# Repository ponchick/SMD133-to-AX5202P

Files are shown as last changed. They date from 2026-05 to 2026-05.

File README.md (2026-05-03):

# SMD133-to-AX5202P

Adapter PCB from the SMD133 mapper IC to the MMC3 AX5202P.

Several cartridge projects are designed for the AX5202P, but that chip is hard to find, whereas the SMD133 is easier to obtain. This board lets you use the SMD133 in those projects.

Russian version: [`README.ru.md`](README.ru.md)

## Jumper configuration

### `K5K7`

The **K5K7** jumper (on SMD133A the corresponding pin is labeled **K5K6**, on SMD133B — **K5K7**) selects which **additional** register block is active on the SMD133.

- If the jumper is **closed**, the range `$5000–$5005` is used.
- If the jumper is **open** (left open), the range depends on the SMD133 variant:
  - SMD133A → `$6000–$6005`
  - SMD133B → `$7000–$7005`

**Note:** With the jumper open, the chip’s internal pull-down holds the pin to GND. If you want to drive this signal from an external source (for example, from the cartridge PCB), solder to the matching pad on the board and do not bridge the jumper. A closed jumper, conversely, pulls the pin to VCC.  
If you are not planning to experiment with the SMD133, the simplest approach is to leave the jumper unsoldered — this does not affect MMC3 mapper operation.

### `CPU_A1` and `CPU_A12`

The AX5202P does not have these pins, but the SMD133 does.  
These jumpers let you either bring in external address-line signals (for example, from the cartridge PCB) or tie them to ground.

- **Close the jumpers** — the corresponding SMD133 pins are forced to GND. This yields behaviour close to authentic MMC3.
- **Leave them open** — you can feed `CPU_A1` and `CPU_A12` from external circuitry by soldering to the jumper pads.

**Important:** It is not recommended to leave these pins floating (connected neither to ground nor to an external signal). In theory this could lead to unpredictable mapper behaviour, although no one has deliberately verified this.

### `WRAM +CE` and `WRAM WE`

These are **normally closed** jumpers:

- `WRAM +CE` is pulled to `VCC`.
- `WRAM WE` is shorted to the `CPU_RW` signal.

This wiring reproduces AX5202P behaviour, so it is recommended to leave the jumpers as-is.  
If you want to experiment — cut the corresponding jumper.

## License

This project is licensed under **CERN Open Hardware Licence Version 2 – Permissive** (`CERN-OHL-P-2.0`).  
See `LICENSE` for details.

SPDX-License-Identifier: `CERN-OHL-P-2.0`

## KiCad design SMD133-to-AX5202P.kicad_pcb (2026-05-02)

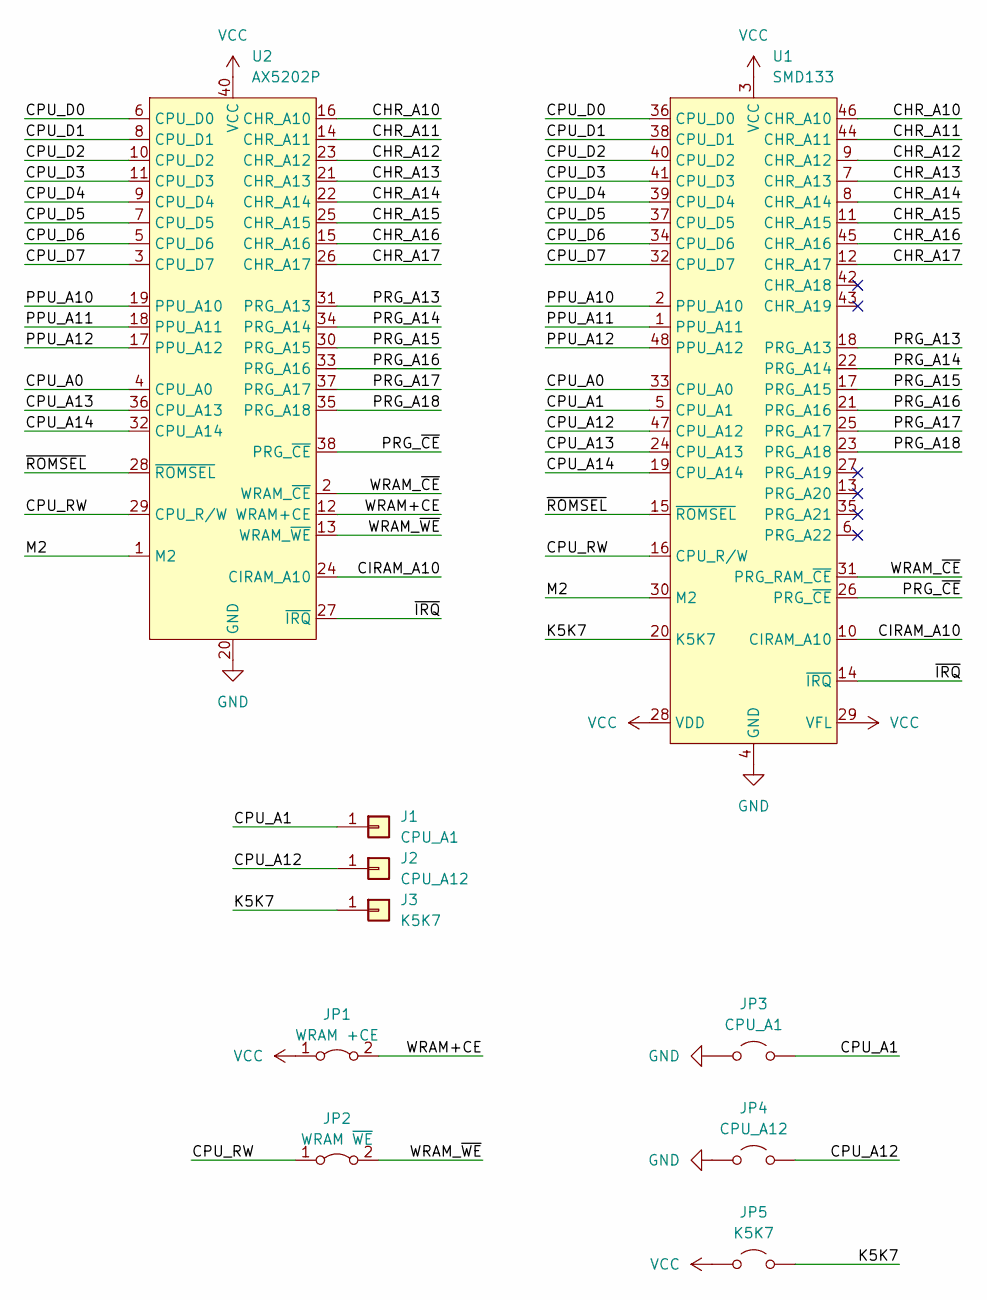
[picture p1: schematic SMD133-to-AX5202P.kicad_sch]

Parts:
J1: CPU_A1; TestPoint_THTPad_D2.0mm_Drill1.0mm
J2: CPU_A12; TestPoint_THTPad_D2.0mm_Drill1.0mm
J3: K5K7; TestPoint_THTPad_D2.0mm_Drill1.0mm
JP1: WRAM +CE; SolderJumper-2_P1.3mm_Bridged_Pad1.0x1.5mm
JP2: WRAM ~{WE}; SolderJumper-2_P1.3mm_Bridged_Pad1.0x1.5mm
JP3: CPU_A1; SolderJumper-2_P1.3mm_Open_TrianglePad1.0x1.5mm
JP4: CPU_A12; SolderJumper-2_P1.3mm_Open_TrianglePad1.0x1.5mm
JP5: K5K7; SolderJumper-2_P1.3mm_Open_TrianglePad1.0x1.5mm
U1: SMD133; LQFP-48_7x7mm_P0.5mm
U2: AX5202P; DIP-40_W15.24mm

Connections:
/CHR_A10: U1.46 (CHR_A10), U2.16 (CHR_A10)
/CHR_A11: U1.44 (CHR_A11), U2.14 (CHR_A11)
/CHR_A12: U1.9 (CHR_A12), U2.23 (CHR_A12)
/CHR_A13: U1.7 (CHR_A13), U2.21 (CHR_A13)
/CHR_A14: U1.8 (CHR_A14), U2.22 (CHR_A14)
/CHR_A15: U1.11 (CHR_A15), U2.25 (CHR_A15)
/CHR_A16: U1.45 (CHR_A16), U2.15 (CHR_A16)
/CHR_A17: U1.12 (CHR_A17), U2.26 (CHR_A17)
/CIRAM_A10: U1.10 (CIRAM_A10), U2.24 (CIRAM_A10)
/CPU_A0: U1.33 (CPU_A0), U2.4 (CPU_A0)
/CPU_A1: J1.1, JP3.2 (B), U1.5 (CPU_A1)
/CPU_A12: J2.1, JP4.2 (B), U1.47 (CPU_A12)
/CPU_A13: U1.24 (CPU_A13), U2.36 (CPU_A13)
/CPU_A14: U1.19 (CPU_A14), U2.32 (CPU_A14)
/CPU_D0: U1.36 (CPU_D0), U2.6 (CPU_D0)
/CPU_D1: U1.38 (CPU_D1), U2.8 (CPU_D1)
/CPU_D2: U1.40 (CPU_D2), U2.10 (CPU_D2)
/CPU_D3: U1.41 (CPU_D3), U2.11 (CPU_D3)
/CPU_D4: U1.39 (CPU_D4), U2.9 (CPU_D4)
/CPU_D5: U1.37 (CPU_D5), U2.7 (CPU_D5)
/CPU_D6: U1.34 (CPU_D6), U2.5 (CPU_D6)
/CPU_D7: U1.32 (CPU_D7), U2.3 (CPU_D7)
/CPU_RW: JP2.1 (A), U1.16 (CPU_R/W), U2.29 (CPU_R/W)
/K5K7: J3.1, JP5.2 (B), U1.20 (K5K7)
/M2: U1.30 (M2), U2.1 (M2)
/PPU_A10: U1.2 (PPU_A10), U2.19 (PPU_A10)
/PPU_A11: U1.1 (PPU_A11), U2.18 (PPU_A11)
/PPU_A12: U1.48 (PPU_A12), U2.17 (PPU_A12)
/PRG_A13: U1.18 (PRG_A13), U2.31 (PRG_A13)
/PRG_A14: U1.22 (PRG_A14), U2.34 (PRG_A14)
/PRG_A15: U1.17 (PRG_A15), U2.30 (PRG_A15)
/PRG_A16: U1.21 (PRG_A16), U2.33 (PRG_A16)
/PRG_A17: U1.25 (PRG_A17), U2.37 (PRG_A17)
/PRG_A18: U1.23 (PRG_A18), U2.35 (PRG_A18)
/PRG_~CE: U1.26 (PRG_~CE), U2.38 (PRG_~CE)
/WRAM+CE: JP1.2 (B), U2.12 (WRAM+CE)
/WRAM_~CE: U1.31 (PRG_RAM_~CE), U2.2 (WRAM_~CE)
/WRAM_~WE: JP2.2 (B), U2.13 (WRAM_~WE)
/~IRQ: U1.14 (~IRQ), U2.27 (~IRQ)
/~ROMSEL: U1.15 (~ROMSEL), U2.28 (~ROMSEL)
GND: JP3.1 (A), JP4.1 (A), U1.4 (GND), U2.20 (GND)
VCC: JP1.1 (A), JP5.1 (A), U1.3 (VCC), U1.28 (VDD), U1.29 (VFL), U2.40 (VCC)

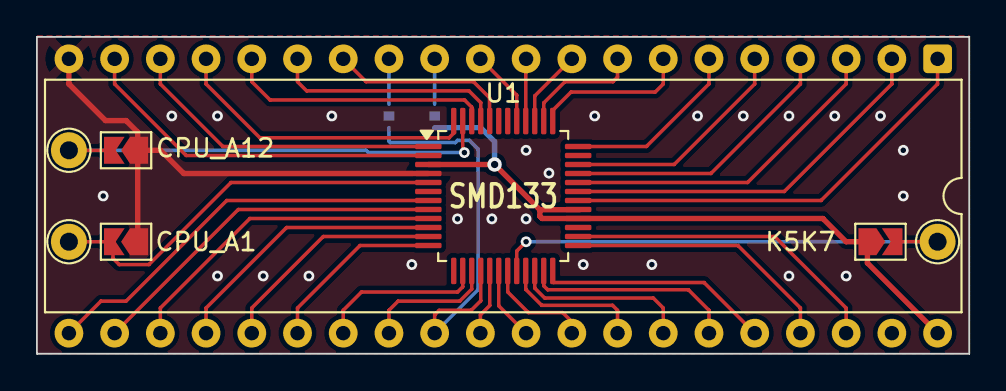
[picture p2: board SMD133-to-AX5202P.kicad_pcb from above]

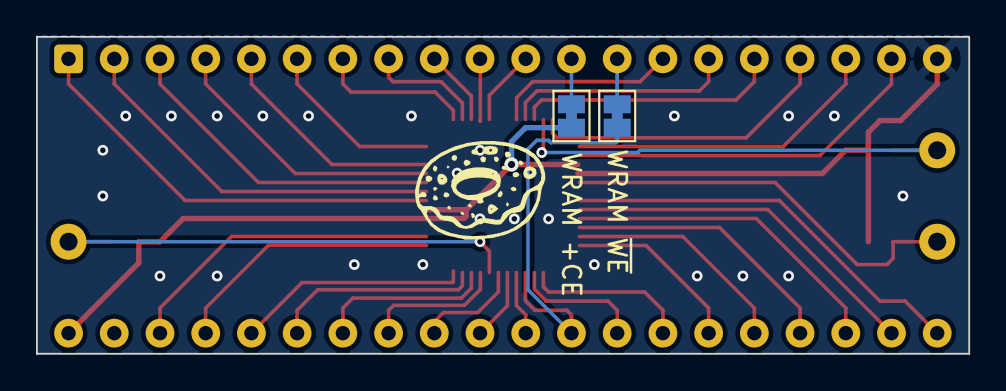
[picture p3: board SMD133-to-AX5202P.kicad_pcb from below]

Board: 2 copper layers, 51.8 x 17.6 mm, 11 parts (3 on the bottom side), 42 nets.

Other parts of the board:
LOGO#: LOGO; ponchick
